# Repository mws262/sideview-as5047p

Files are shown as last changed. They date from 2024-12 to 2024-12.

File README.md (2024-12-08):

# Sideview Tech AS5047P Breakout Board

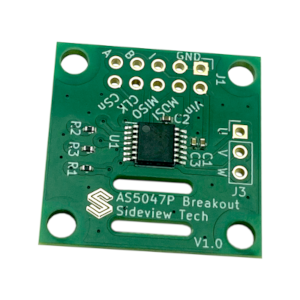
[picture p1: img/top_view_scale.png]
AS5047P Breakout Board


A compact breakout board for the **AS5047P** magnetic rotary position sensor. I sell them on Amazon [here](https://a.co/d/bI0XgS7). This repo contains documentation and CAD to help you get started and develop with this board.

Note that I am not affiliated with AMS Osram, the maker of the sensor chip itself.

## Documents
- [AS5047P official datasheet](http://bit.ly/as5047p)
- [Quick guide for this board](docs/sideview_as5047p_quick_guide.pdf)

## Jumpers
**By default, this breakout board is set to run on 3.3V and communicate over SPI. If you are fine with this, no need to read this section.** 

Input voltage and communication output can be changed by soldering/cutting jumpers on the board. Note that I've found the AS5047P to be very tolerant, and it will possibly run ok anyway. However, this goes against the datasheet recommendations and may reduce the life of the IC or immediately fry it.

SPI Jumpers

If SPI is not being used (i.e, you're using ABI or UVW), all three of these jumpers should be individually bridged with solder. This enables a pull-up resistor on CSn and pull-down resistors on CLK and MOSI. These resistors are already on the board and just need the jumper pads to be connected.

3V/5V Jumper

To enable 5V power input on Vin, this jumper should be cut. There is a small trace between the two exposed pads that can be cut with a razor blade. It's a good idea to check (dis)continuity between the pads to make sure you've cut the trace completely. The board can be reverted to 3.3V operation by soldering the jumper back again.

Essentially, this jumper determines whether or not the internal 3.3V voltage regulator of the AS5047P is bypassed or not. See the datasheet for more info.

## Magnets
The included magnet is:
- Diametrically magnetized
- 6mm diameter, 2.5mm thickness
- N45H grade neodymium magnet

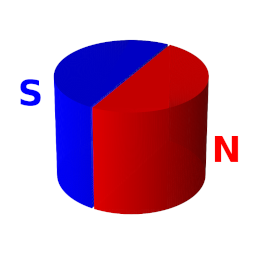
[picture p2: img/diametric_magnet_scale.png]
diametric magnet diagram


Any diametrically-magnetized motor should work with this sensor. A lot of motors intended for robotics have a magnet already built-in on the shaft on the back of the motor. It's worth checking anyway. For quickly telling how something is magnetized, I highly recommend this [viewing film](https://www.amazon.com/dp/B0BCFM83XB).

### Magnet mounting
Typically the magnet is attached to the end of a rotating shaft and a few mm above the sensor chip. For initial testing, you can often just have the magnet stick to the end of a steel shaft on its own. Over time though, it will slip and cause the zero-position to shift. A dab of superglue between the magnet and the shaft is often good enough for prototypes. For more durability, you can graduate to a 3D print or a shaft coupler.

## Software Libraries
I take no credit for these libraries, though I do like them!
- [Arduino AS5047P Library](https://github.com/jonas-merkle/AS5047P)
   - Easiest way to get started with the sensor over SPI.
   - Install with the Arduino library manager.
- [Arduino quadrature encoder (AB) encoder library](https://github.com/PaulStoffregen/Encoder)
   - Install with the Arduino library manager.
- [STM32 HAL/ other platform library](https://github.com/ziteh/as5047p-driver)
   - Easy to use with platformio, e.g. `lib_deps = ziteh/as5047-driver@^2.0.0`
   - Don't use for stm32duino. The Arduino libraries are more suitable.

## Schematic
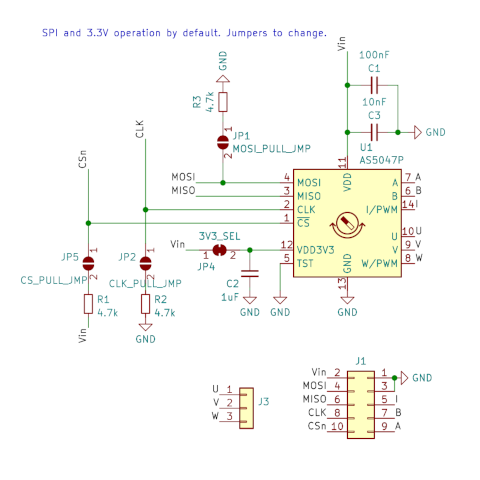
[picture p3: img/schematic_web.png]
Schematic


## Dimensions
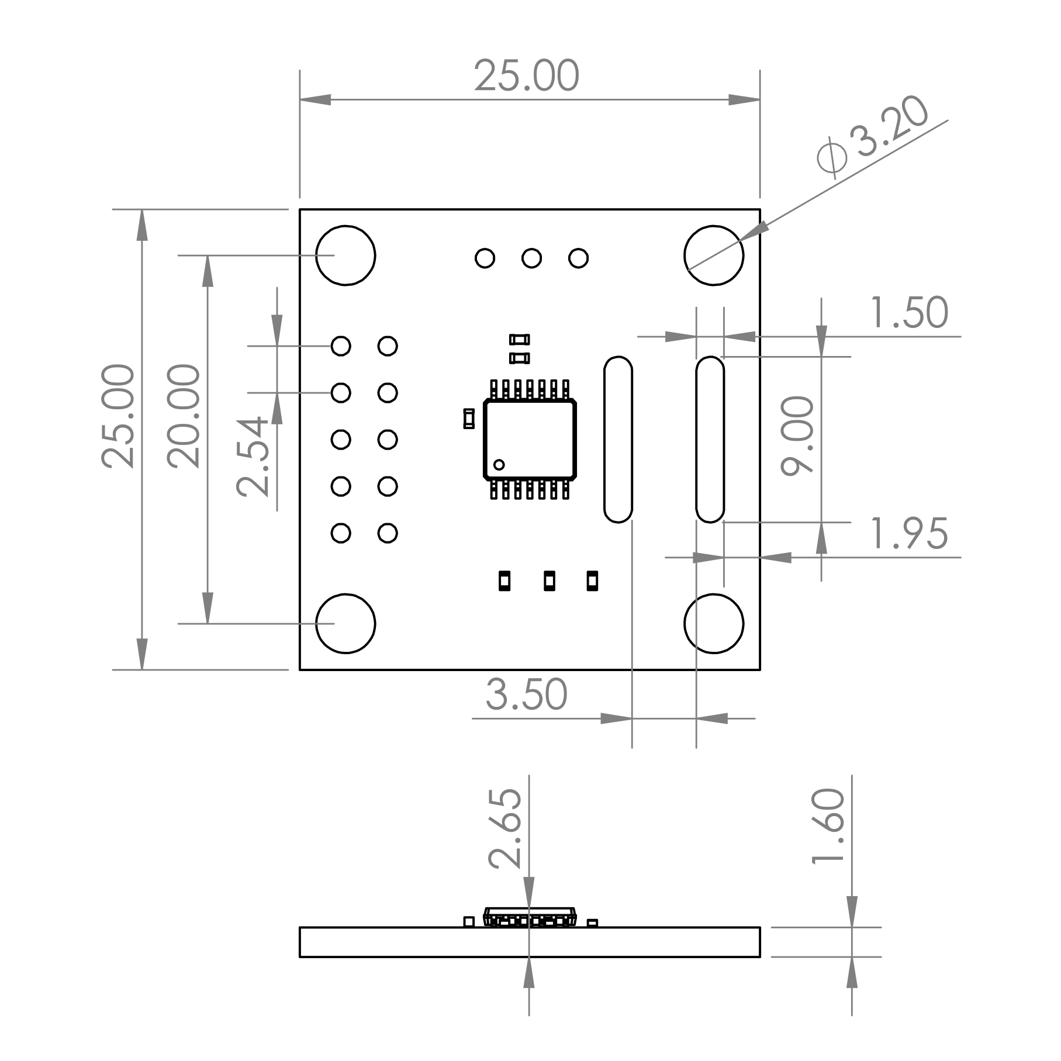
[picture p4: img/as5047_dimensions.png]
dimensions


## Contact
For questions, email [matt@sideview.bike](mailto:matt@sideview.bike).

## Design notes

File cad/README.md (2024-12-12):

# CAD Models
STEP files for the Sideview AS5047P breakout board and a few example mounts. The mounts can be 3D printed, and the board is meant to snap into place with a little pressure. I am open to accepting or designing other models for specific motors if there is demand.

## [as5047_breakout.step](as5047_breakout.step)
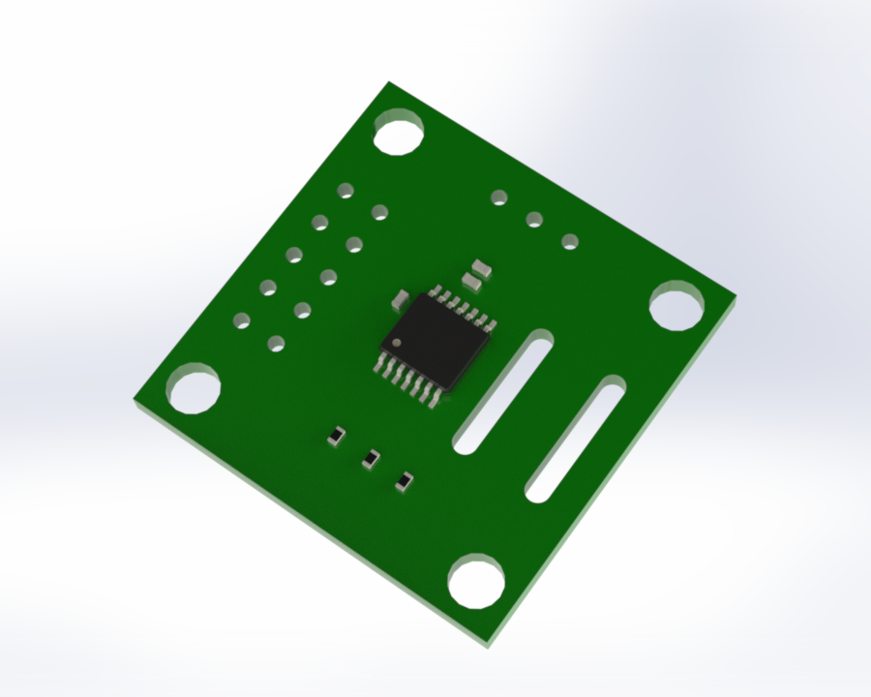
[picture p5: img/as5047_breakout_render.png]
Full board render

Full board with components.

## [evm_mb_adapter.step](evm_mb_adapter.STEP)
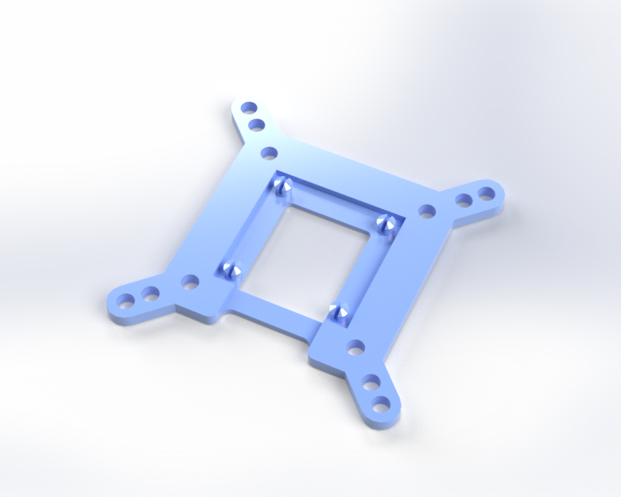
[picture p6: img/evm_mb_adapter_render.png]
evm_mb_adapter render

This is an adapter for making the Sideview board fit where AMS's AS5X47P_TS_EVM_MB would. It's a little thicker in total, but the holes should line up.

## [mot_bracket_example.step](mot_bracket_example.STEP)
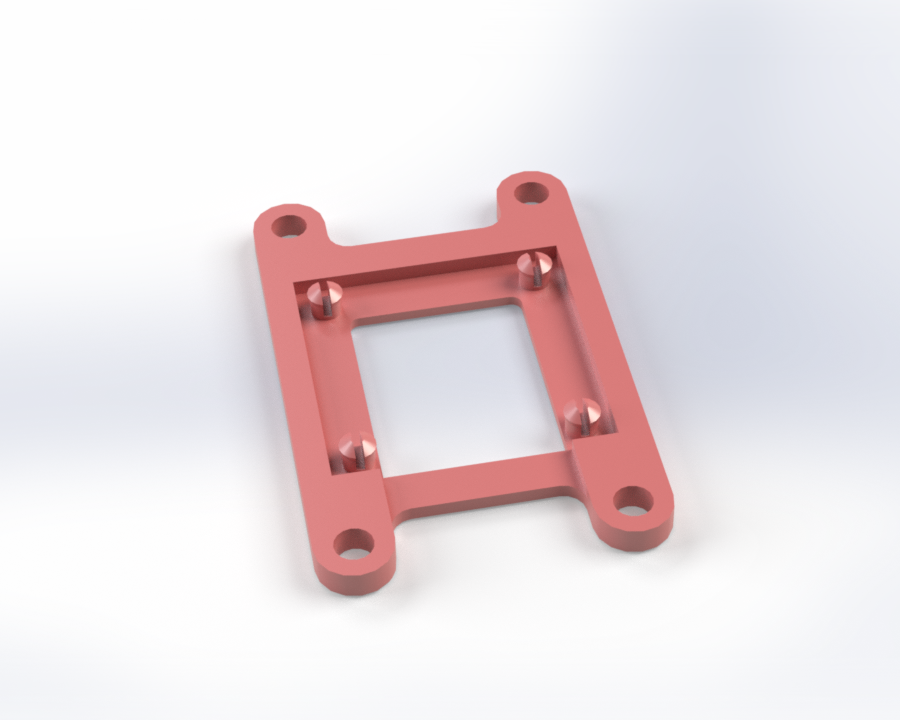
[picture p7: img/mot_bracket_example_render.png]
Example bracket render

Another example mounting bracket. It fits [TODO] motor, but should be easy to adapt to other applications.

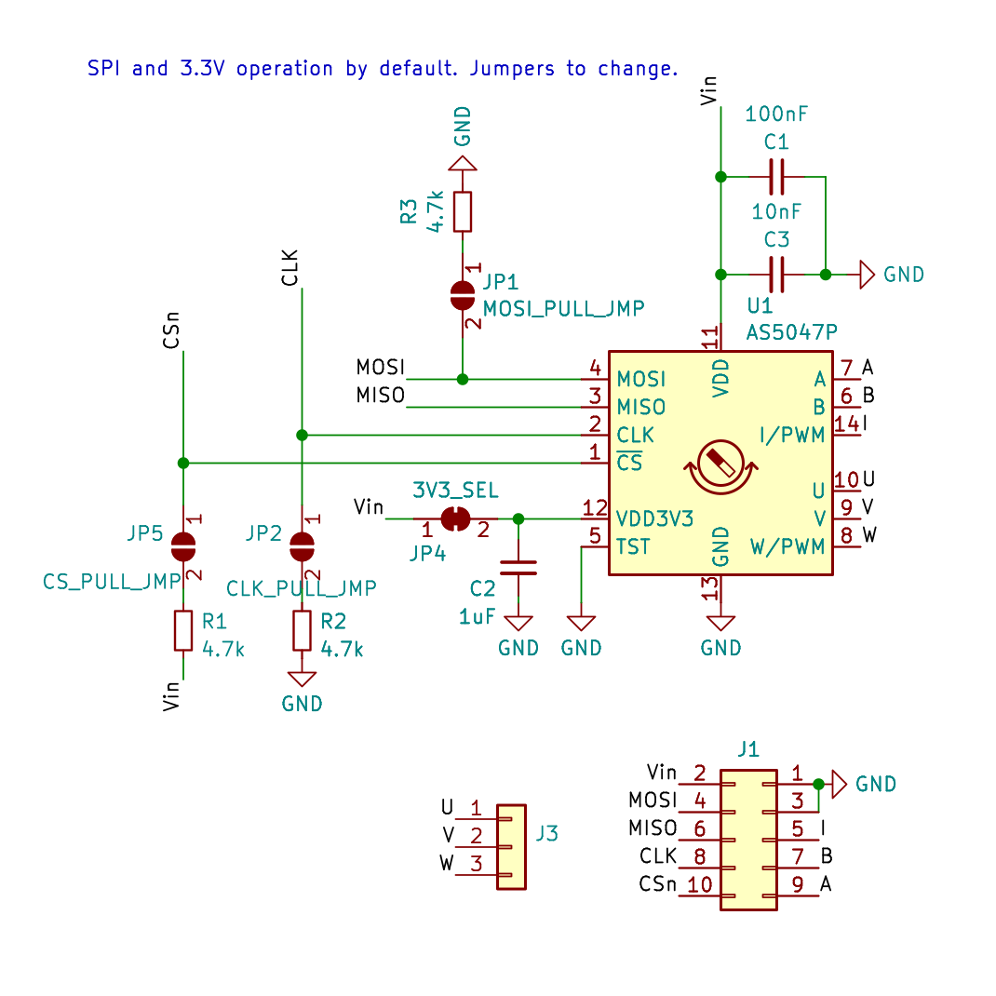
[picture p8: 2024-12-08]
img/schematic.png

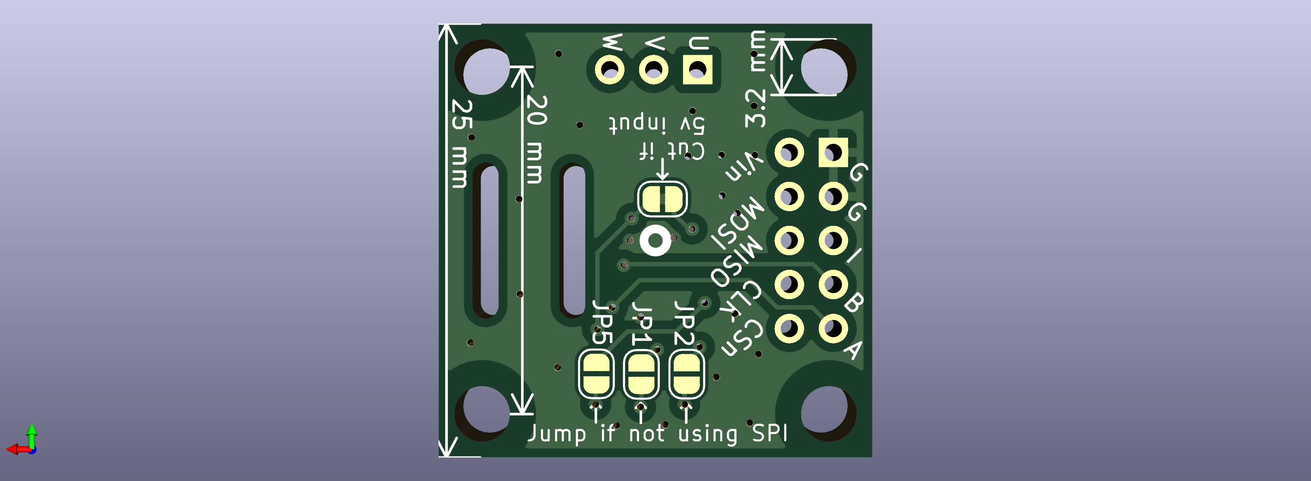
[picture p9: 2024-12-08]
img/as5047_breakout_bott.png

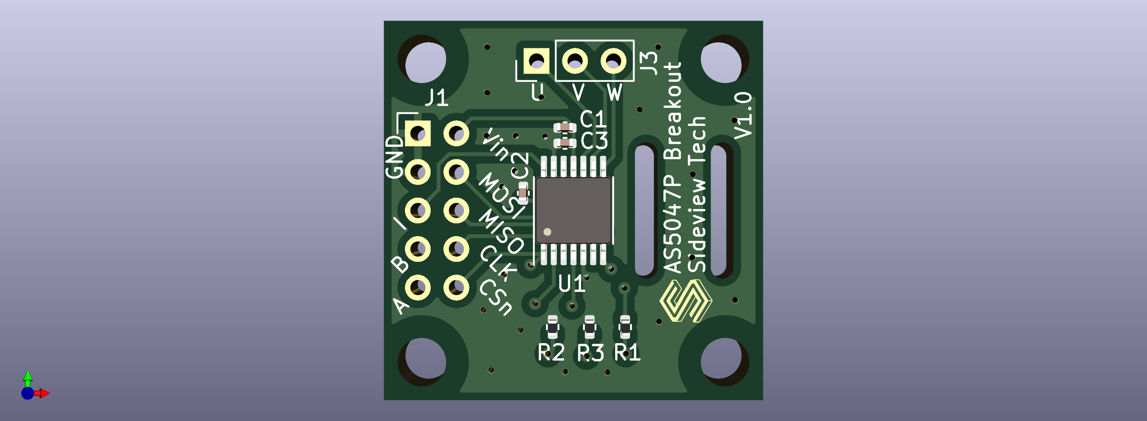
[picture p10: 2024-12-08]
img/as5047_breakout.png

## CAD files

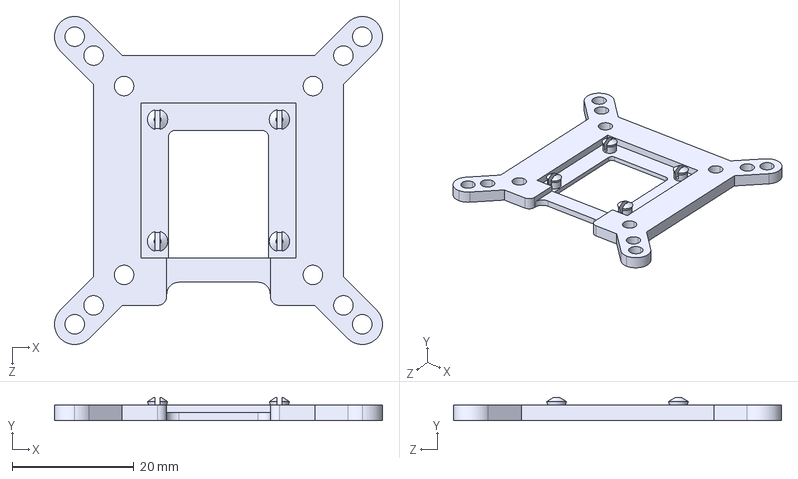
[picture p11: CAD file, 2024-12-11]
cad/evm_mb_adapter.STEP
53.8 x 3.85 x 53.8 mm

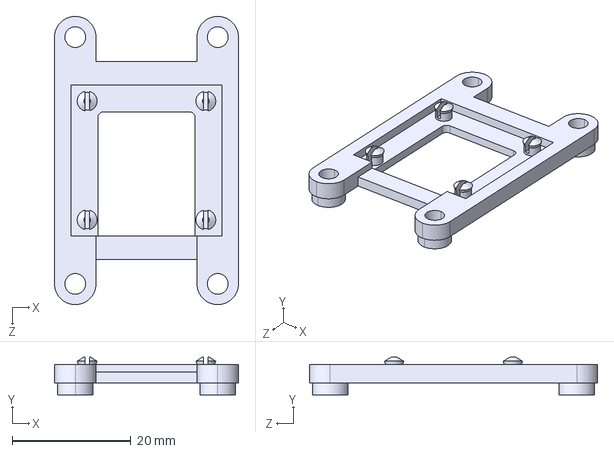
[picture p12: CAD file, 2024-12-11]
cad/mot_bracket_example.STEP
31.0 x 6.40 x 48.6 mm

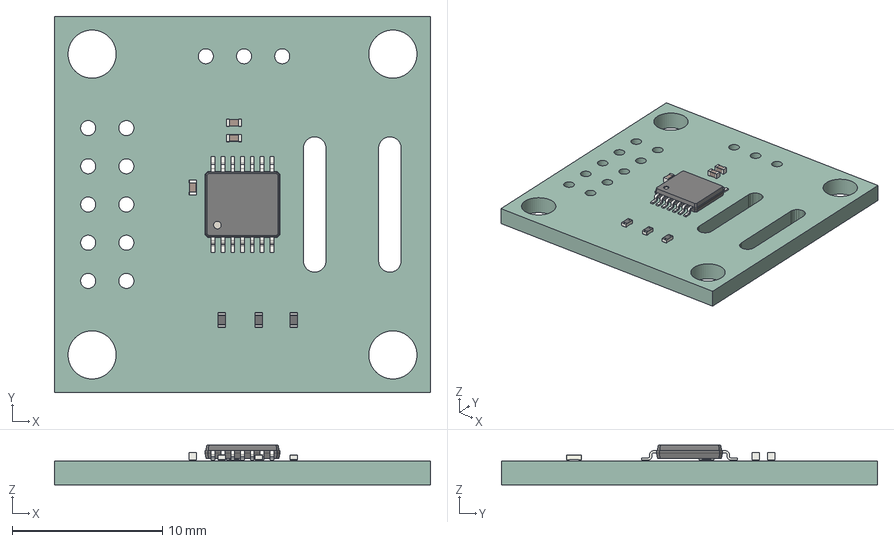
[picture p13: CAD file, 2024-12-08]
cad/as5047_breakout.step
25.0 x 25.0 x 2.65 mm
TSSOP_14_44x5mm_P065mm
R_0402_1005Metric x 3
C_0402_1005Metric x 3
_autosave-as5047_breakout PCB

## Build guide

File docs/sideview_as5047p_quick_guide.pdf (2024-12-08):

## AS5047P breakout board

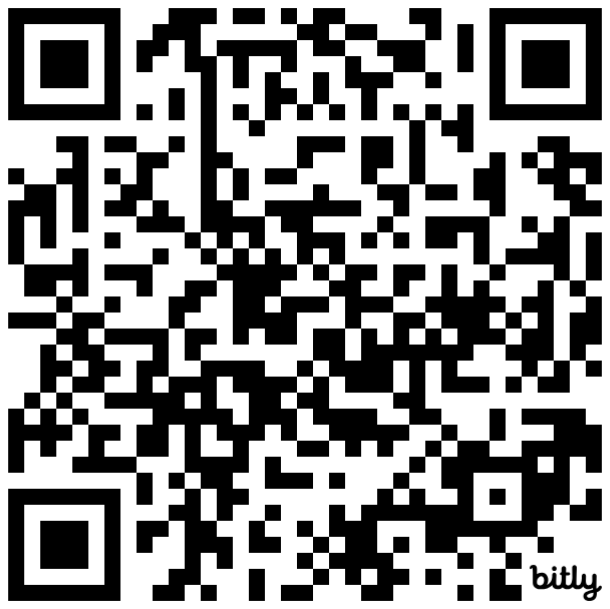
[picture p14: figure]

TL;DR SPI and 3.3V operation are default. If you want something else, change some jumpers.
For more resources, scan the QR code

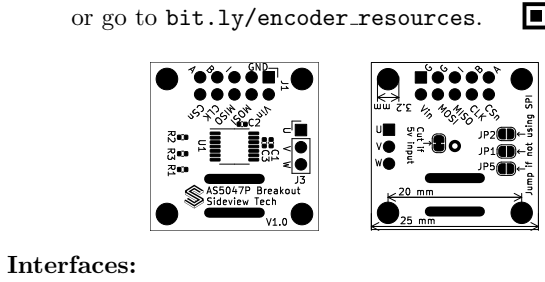
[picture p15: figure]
or go to bit.ly/encoder resources.; Interfaces:

- SPI (default) is the most flexible way to get absolute position from the sensor. Connect to VIN, MOSI, MISO, CLK, CSn, and GND. When only one-way communication is required, like when interfacing with a VESC motor controller, MOSI may be connected directly to VIN. For use with Arduino, search for AS5047P in the library manager.
- ABI, quadrature encoder mode offers broad compatibility. Absolute position is known after the first index pulse (once per revolution). The I (or Z) pin can be left unconnected if absolute position is unnecessary.
- UVW commutation signals are similar to the outputs of the three hall sensors built-in to some brushless motors.
Sideview | Questions? Email matt@sideview.bike

Jumpers:

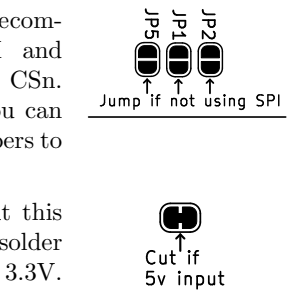
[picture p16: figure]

If not using SPI, the datasheet recommends pull-up resistors on CLK and MISO and a pull-down resistor on CSn. These resistors are built-in, and you can individually solder across the 3 jumpers to enable them.

If powering the board with 5V, cut this jumper with an x-acto knife. Re-solder this jumper if you ever return to 3.3V. Never apply more than 5V.

Sensor magnet:

Only diametrically-magnetized magnets (like the included one) will work. Most similar-looking magnets are axially-magnetized! The magnet should be mounted several mm above the AS5047P chip. For testing purposes, you can secure the magnet on the end of a shaft with a dab of superglue. If sensor readings cut in and out, the magnet is probably too far, too close, or has too much misalignment from the center of the sensor.

Wiring: A 2.54mm pitch header is
included for use with the common
DuPont jumper cables. For more
permanent connection, a ribbon cable can be routed through the strainrelief slots in the PCB as shown.

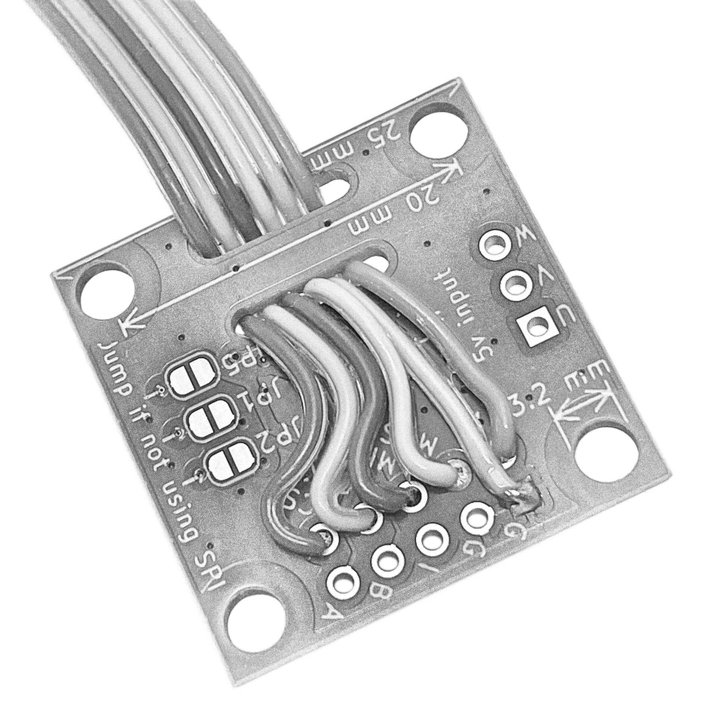
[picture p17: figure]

Sideview | Questions? Email matt@sideview.bike

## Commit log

2024-12-08 Added some resources. Need to upload a few more CAD models
    [as5047_breakout.step]
2024-12-11 Added missing STEP files
    [evm_mb_adapter.STEP, mot_bracket_example.STEP]
2024-12-12 fixed links on cad page
